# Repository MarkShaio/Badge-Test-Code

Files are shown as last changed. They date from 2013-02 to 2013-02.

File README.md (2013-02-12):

Badge-Test-Code
===============
1.All the code here is from openbeacon except an added section in main.c under MSP430_tag directory. Find the do while loop. 
This is where all the checking code lives in. The code currently in the loop is meant to check the joint between the cpu and the 
accelerometer. This code may not work so you must check.

2.The code in comments in the loop works fine. Basically if you run the code and you see LED2 light up then that means at least one of the pins
from the SPI is not connected properly .

3.debug1.ino will let you check whether your switch is working. The LED on board should toggle along with the switch.

4.In "Latest PCB Version", you will find the most up to date version of my board. If you want to use it there is one thing that you need to 
change. The bottom right corner of the switch must not be covered by the ground plane. So remove the ground plane on the right side
and recreate that ground plane.

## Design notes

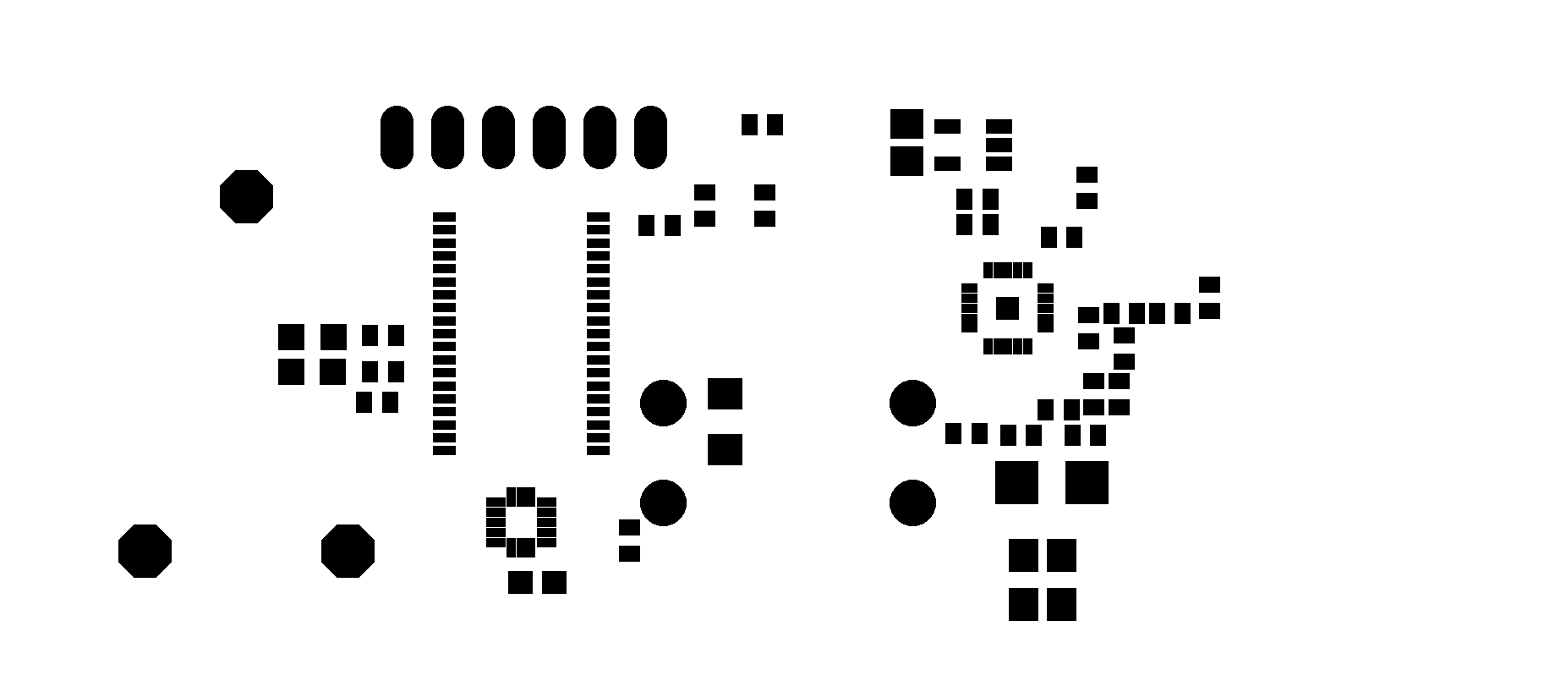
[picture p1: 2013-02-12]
Latest PCB version/With 3D model/eagleUp/eagleUp_nRF24L01-Chip-v12_top_mask.png

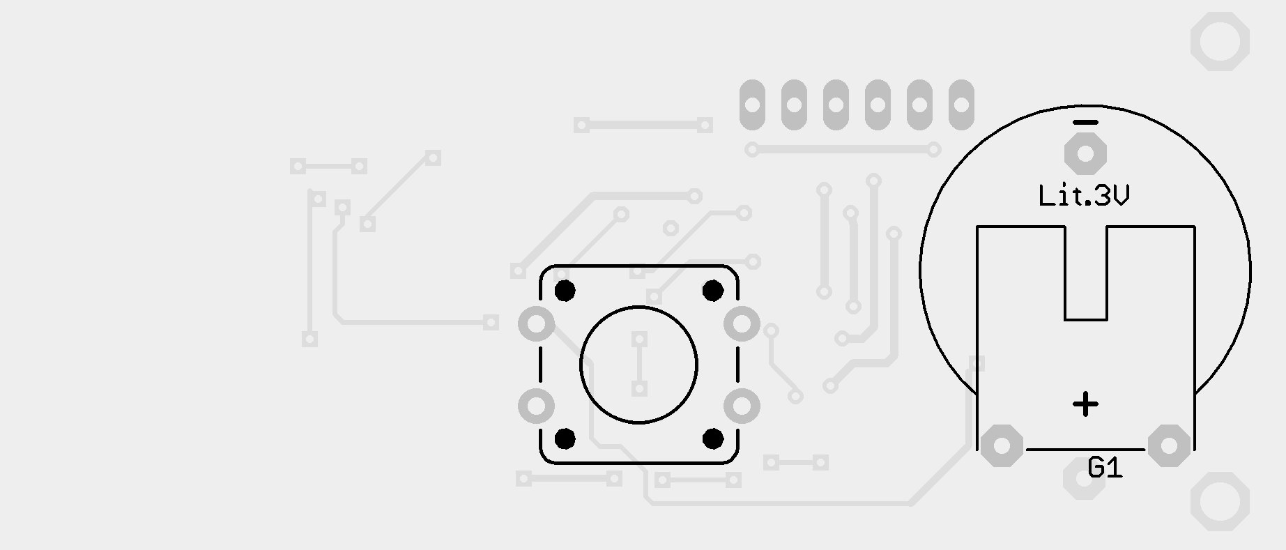
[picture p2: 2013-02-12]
Latest PCB version/With 3D model/eagleUp/eagleUp_nRF24L01-Chip-v12_board_bottom.png

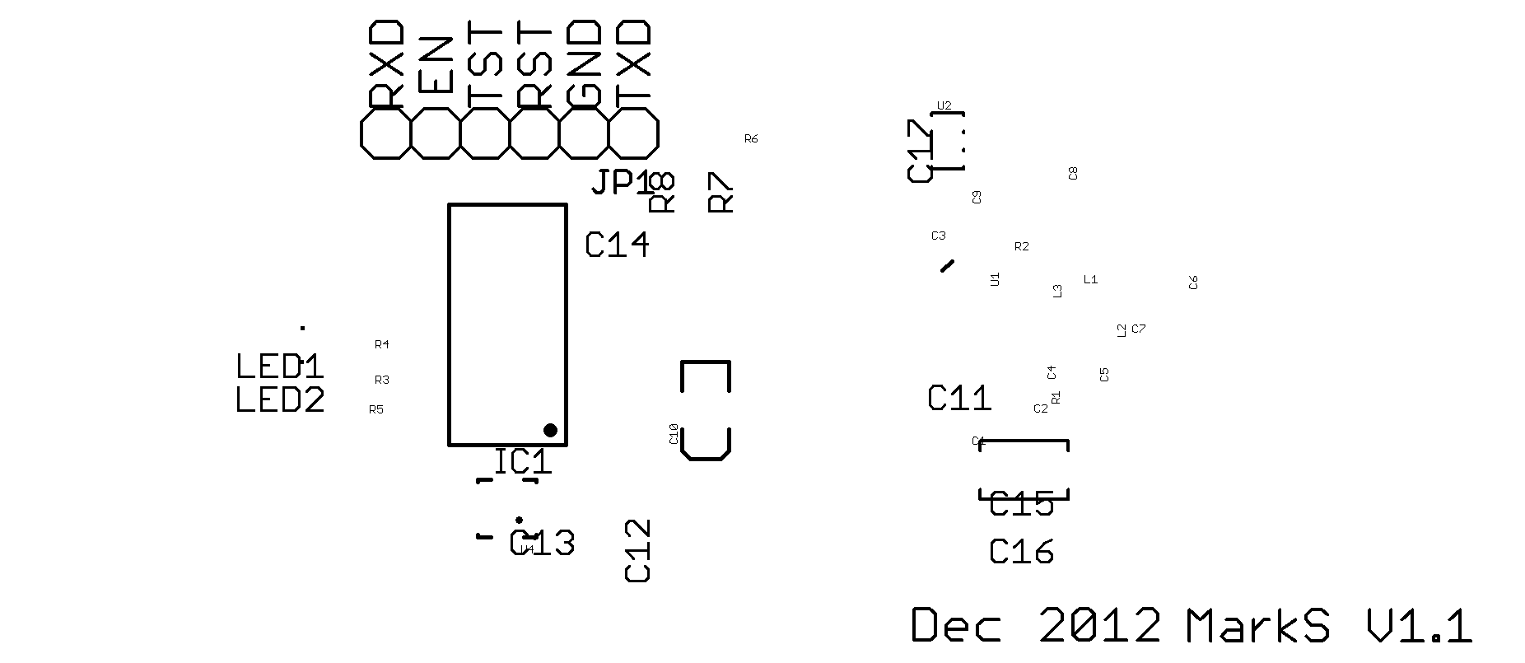
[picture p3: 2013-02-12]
Latest PCB version/With 3D model/eagleUp/eagleUp_nRF24L01-Chip-v12_top_silk.png

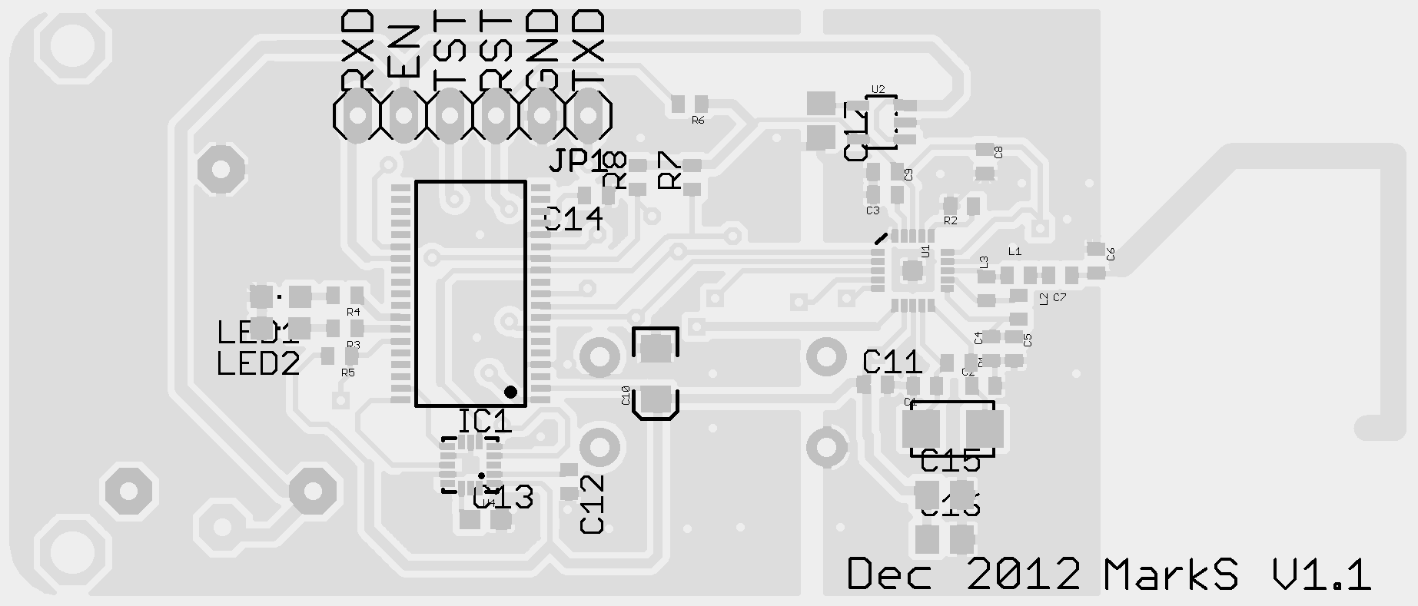
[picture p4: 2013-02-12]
Latest PCB version/With 3D model/eagleUp/eagleUp_nRF24L01-Chip-v12_board_top.png

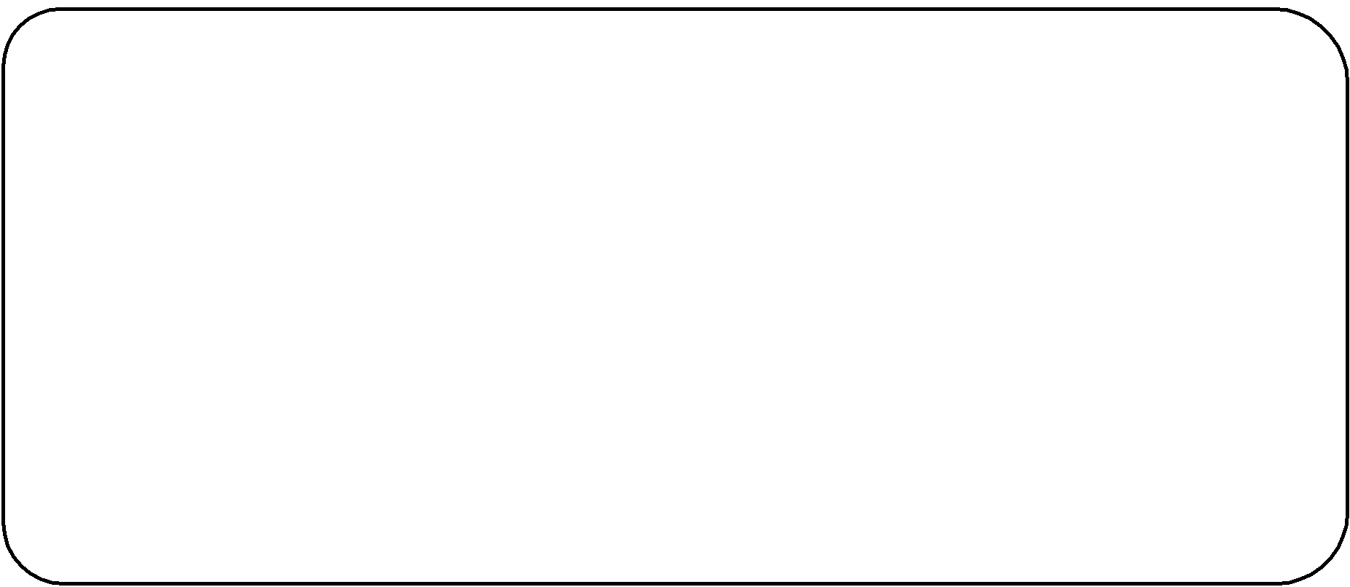
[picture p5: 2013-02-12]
Latest PCB version/With 3D model/eagleUp/eagleUp_nRF24L01-Chip-v12_outline.png

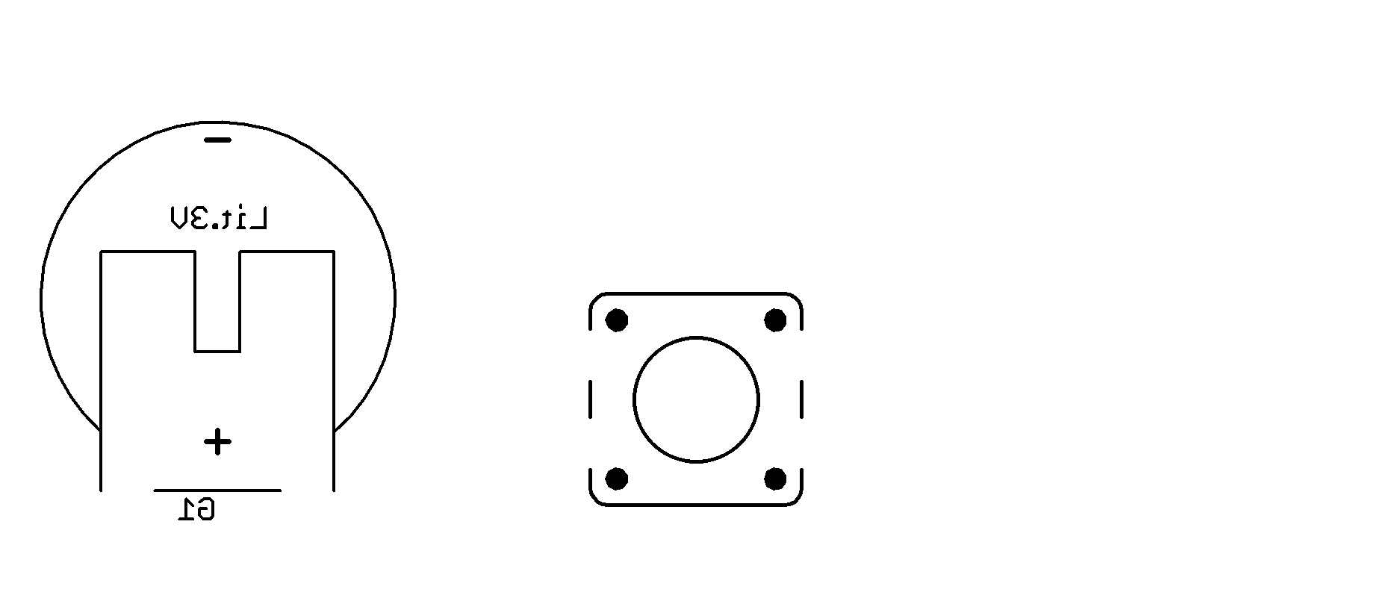
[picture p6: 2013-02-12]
Latest PCB version/With 3D model/eagleUp/eagleUp_nRF24L01-Chip-v12_bottom_silk.png

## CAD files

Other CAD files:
Latest PCB version/With 3D model/3D model.skp

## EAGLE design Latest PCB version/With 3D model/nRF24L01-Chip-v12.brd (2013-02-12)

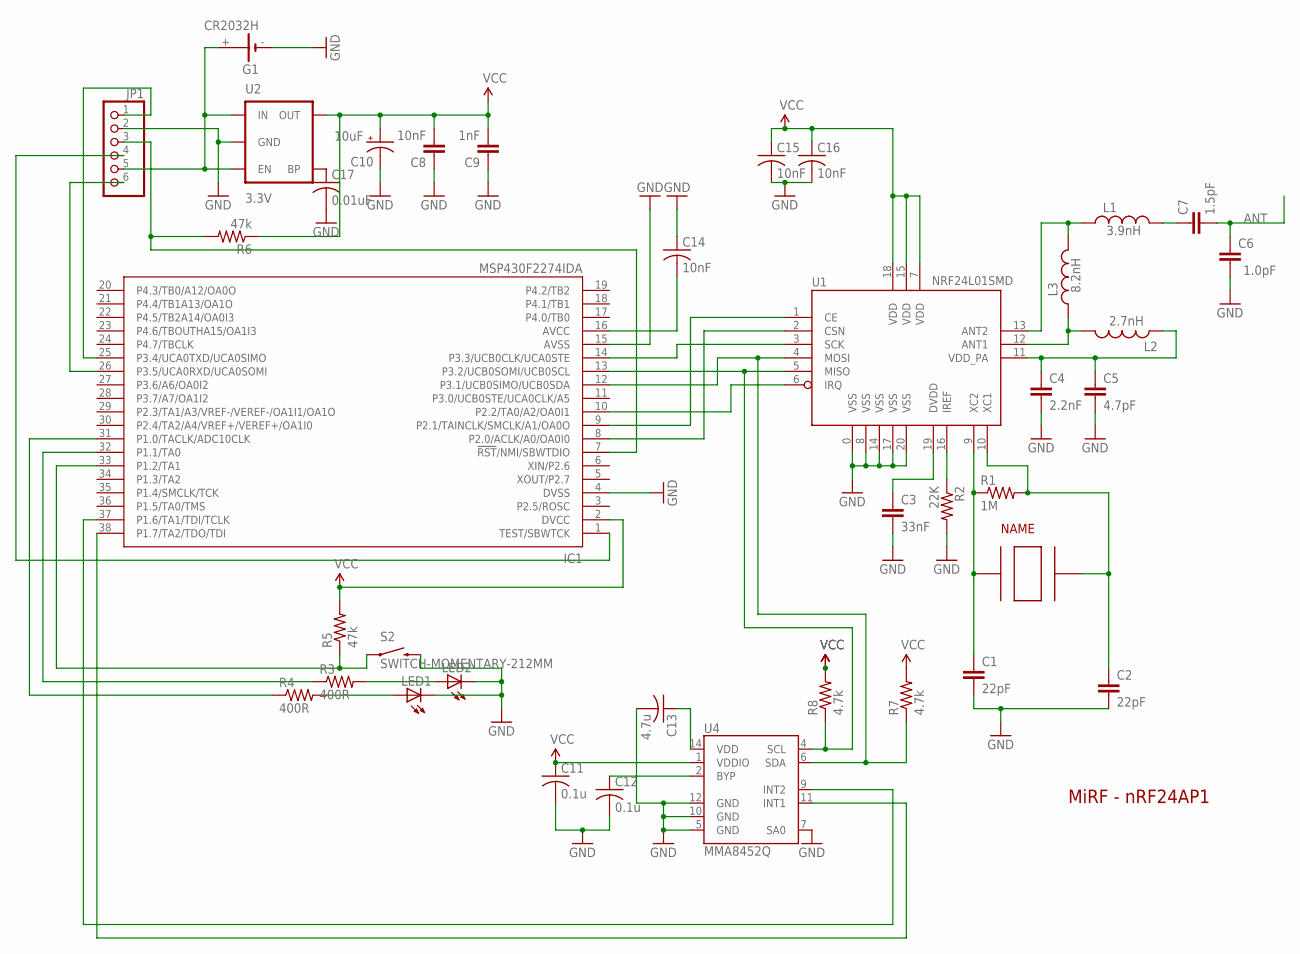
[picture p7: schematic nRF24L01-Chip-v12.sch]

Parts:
C1, C2: 22pF; C0402
C3: 33nF; C0402
C4: 2.2nF; C0402
C5: 4.7pF; C0402
C6: 1.0pF; C0402
C7: 1.5pF; C0402
C8, C14: 10nF; C0402
C9: 1nF; C0402
C10: 10uF; EIA3216
C11, C12: 0.1u; C0402
C13: 4.7u; C0603
C15, C16: 10nF; C0805
C17: 0.01uF; C0805
G1: CR2032H
IC1: MSP430F2274IDA; TSSOP38_R-PDSO-G38-DA
JP1: PINHD-1X6; 1X06
L1: 3.9nH; C0402
L2: 2.7nH; C0402
L3: 8.2nH; C0402
LED1, LED2: LEDCHIPLED_0805; CHIPLED_0805
Q1: SMAQ-5032A; CRSYTAL1
R1: 1M; C0402
R2: 22K; C0402
R3, R4: 400R; C0402
R5, R6: 47k; C0402
R7, R8: 4.7k; R0402
S2: SWITCH-MOMENTARY-212MM; TACTILE-PTH-12MM
U1: NRF24L01SMD; QFN20
U2: 3.3V; SOT23-5
U4: MMA8452Q; QFN-16_0.5MM

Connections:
ANT: C6.2, C7.2
GND: C1.2, C2.2, C3.2, C4.2, C5.2, C6.1, C8.1, C9.1, C10.C (-), C11.2, C12.2, C13.2, C14.1, C15.2, C16.2, C17.2, G1.-, IC1.4 (DVSS), IC1.15 (AVSS), JP1.2, LED1.C, LED2.C, R2.2, S2.3 (2), U1.0 (VSS), U1.8 (VSS), U1.14 (VSS), U1.17 (VSS), U1.20 (VSS), U2.2 (GND), U4.5 (GND), U4.7 (SA0), U4.10 (GND), U4.12 (GND)
unnamed: C1.1, Q1.P$3, R1.1, U1.9 (XC2)
unnamed: IC1.1 (TEST/SBWTCK), JP1.4
unnamed: L2.2, L3.1, U1.12 (ANT1)
unnamed: R2.1, U1.16 (IREF)
unnamed: C3.1, U1.19 (DVDD)
unnamed: L1.1, L3.2, U1.13 (ANT2)
unnamed: C4.1, C5.1, L2.1, U1.11 (VDD_PA)
unnamed: IC1.9 (P2.1/TAINCLK/SMCLK/A1/OA0O), U1.1 (CE)
unnamed: C7.1, L1.2
unnamed: IC1.8 (P2.0/ACLK/A0/OA0I0), U1.2 (CSN)
unnamed: IC1.14 (P3.3/UCB0CLK/UCA0STE), U1.3 (SCK)
unnamed: IC1.12 (P3.1/UCB0SIMO/UCB0SDA), R7.1, U1.4 (MOSI), U4.6 (SDA)
unnamed: IC1.13 (P3.2/UCB0SOMI/UCB0SCL), R8.1, U1.5 (MISO), U4.4 (SCL)
unnamed: IC1.25 (P3.4/UCA0TXD/UCA0SIMO), JP1.1
unnamed: IC1.10 (P2.2/TA0/A2/OA0I1), U1.6 (IRQ)
unnamed: IC1.32 (P1.1/TA0), R3.1
unnamed: LED2.A, R3.2
unnamed: LED1.A, R4.2
unnamed: IC1.33 (P1.2/TA1), R5.1, S2.1
unnamed: C17.1, U2.4 (BP)
unnamed: IC1.26 (P3.5/UCA0RXD/UCA0SOMI), JP1.6
unnamed: C14.2, IC1.16 (AVCC)
unnamed: IC1.31 (P1.0/TACLK/ADC10CLK), R4.1
unnamed: C2.1, Q1.P$4, R1.2, U1.10 (XC1)
unnamed: IC1.7 (!RST!/NMI/SBWTDIO), JP1.3, R6.2
unnamed: C12.1, U4.2 (BYP)
unnamed: IC1.38 (P1.7/TA2/TDO/TDI), U4.11 (INT1)
unnamed: IC1.37 (P1.6/TA1/TDI/TCLK), U4.9 (INT2)
unnamed: C13.1, U4.14 (VDD)
RAW: G1.+, JP1.5, U2.1 (IN), U2.3 (EN)
VCC: C8.2, C9.2, C10.A (+), C11.1, C15.1, C16.1, IC1.2 (DVCC), R5.2, R6.1, R7.2, R8.2, U1.7 (VDD), U1.15 (VDD), U1.18 (VDD), U2.5 (OUT), U4.1 (VDDIO)

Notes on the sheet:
MiRF - nRF24AP1

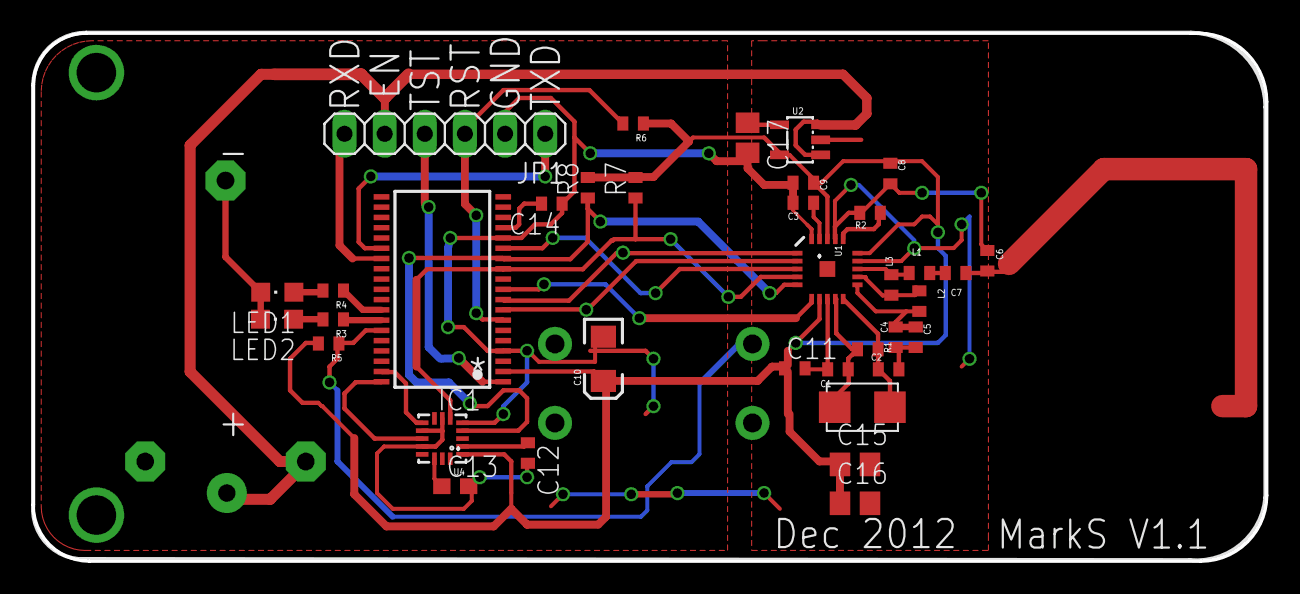
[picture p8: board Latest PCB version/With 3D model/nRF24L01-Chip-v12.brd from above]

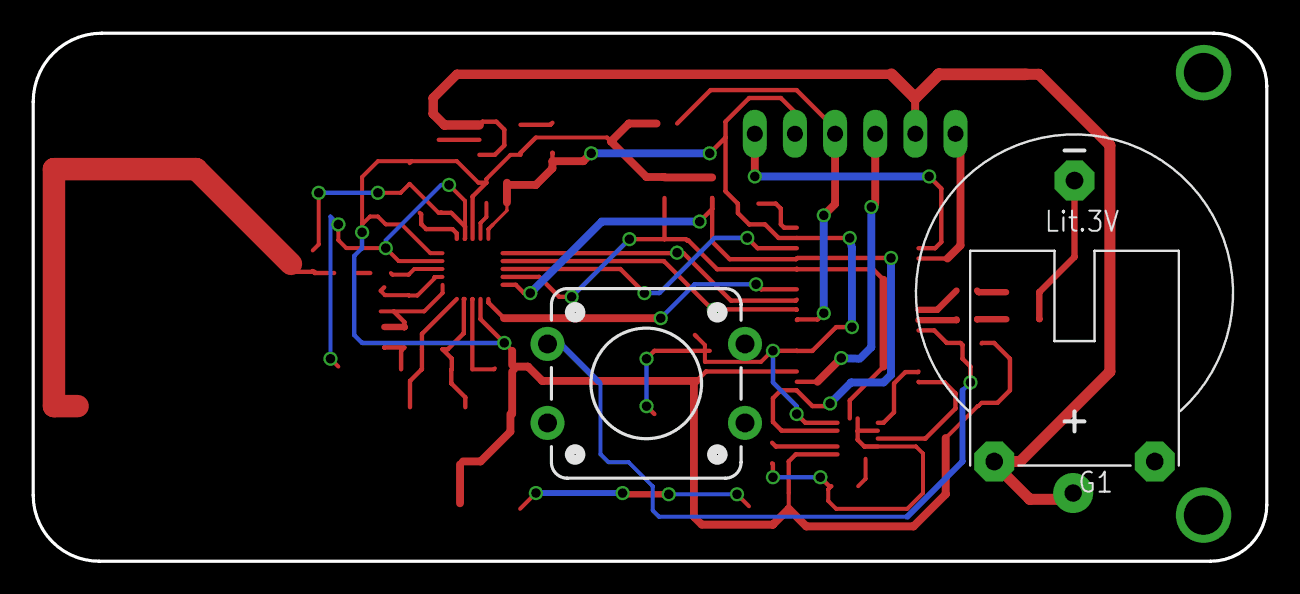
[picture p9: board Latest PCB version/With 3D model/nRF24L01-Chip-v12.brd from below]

Board: 2 copper layers, 78.1 x 33.4 mm, 38 parts (2 on the bottom side), 33 nets.

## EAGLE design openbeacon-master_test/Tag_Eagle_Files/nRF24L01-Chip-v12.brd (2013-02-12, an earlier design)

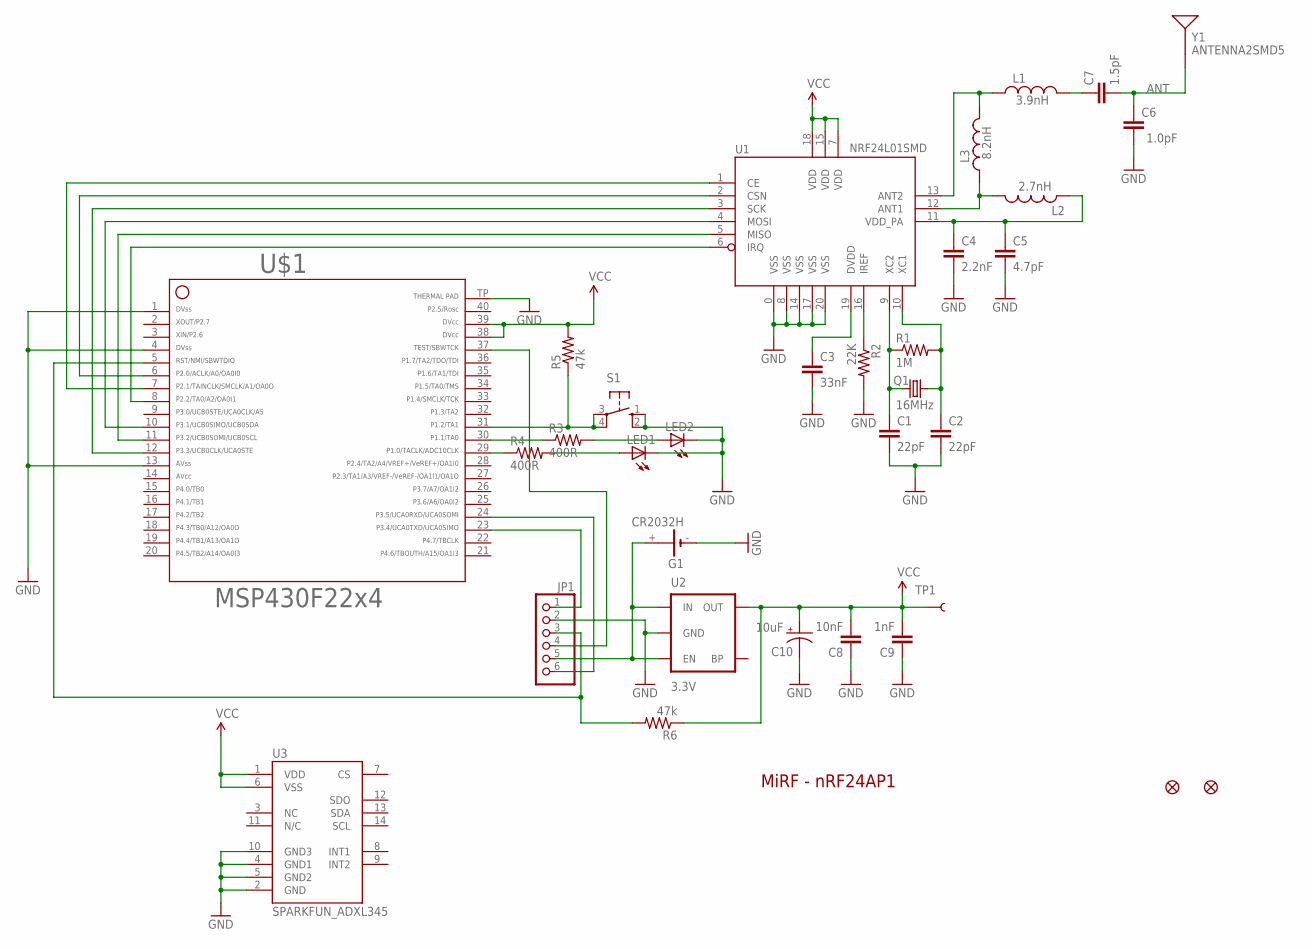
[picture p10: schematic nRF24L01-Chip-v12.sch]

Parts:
C1, C2: 22pF; C0402
C3: 33nF; C0402
C4: 2.2nF; C0402
C5: 4.7pF; C0402
C6: 1.0pF; C0402
C7: 1.5pF; C0402
C8: 10nF; C0402
C9: 1nF; C0402
C10: 10uF; EIA3216
G1: CR2032H
JP1: PINHD-1X6; 1X06
L1: 3.9nH; C0402
L2: 2.7nH; C0402
L3: 8.2nH; C0402
LED1, LED2: LEDCHIPLED_0805; CHIPLED_0805
Q1: 16MHz; CRYSTAL-SMD-5X3
R1: 1M; C0402
R2: 22K; C0402
R3, R4: 400R; C0402
R5, R6: 47k; C0402
S1: 10-XX; B3F-10XX
TP1: TEST-POINT3X5; PAD.03X.05
U1: NRF24L01SMD; QFN20
U2: 3.3V; SOT23-5
U3: SPARKFUN_ADXL345; SPARKFUN_LGA14
U$1: F22X4---RHA40; RHA40
U$2, U$3: FIDUCIAL1X2; FIDUCIAL-1X2
Y1: ANTENNA2SMD5; ANTENNA-CHIP5

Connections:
14: U$1.14
ANT: C6.2, C7.2, Y1.FEED
GND: C1.2, C2.2, C3.2, C4.2, C5.2, C6.1, C8.1, C9.1, C10.C (-), G1.-, JP1.2, LED1.C, LED2.C, R2.2, S1.1 (S), S1.2 (S1), U1.0 (VSS), U1.8 (VSS), U1.14 (VSS), U1.17 (VSS), U1.20 (VSS), U2.2 (GND), U3.2 (GND), U3.4 (GND1), U3.5 (GND2), U3.10 (GND3), U$1.1, U$1.4, U$1.13, U$1.TP
unnamed: C1.1, Q1.1, R1.1, U1.9 (XC2)
unnamed: C2.1, Q1.3 (2), R1.2, U1.10 (XC1)
unnamed: L2.2, L3.1, U1.12 (ANT1)
unnamed: R2.1, U1.16 (IREF)
unnamed: C3.1, U1.19 (DVDD)
unnamed: L1.1, L3.2, U1.13 (ANT2)
unnamed: C4.1, C5.1, L2.1, U1.11 (VDD_PA)
unnamed: U1.4 (MOSI), U$1.10
unnamed: C7.1, L1.2
unnamed: U1.5 (MISO), U$1.11
unnamed: U1.3 (SCK), U$1.12
unnamed: U1.2 (CSN), U$1.6
unnamed: U1.1 (CE), U$1.7
unnamed: R4.1, U$1.29
unnamed: U1.6 (IRQ), U$1.8
unnamed: R3.1, U$1.30
unnamed: LED2.A, R3.2
unnamed: LED1.A, R4.2
unnamed: R5.1, S1.3, S1.4 (P1), U$1.31
unnamed: JP1.1, U$1.23
unnamed: JP1.6, U$1.24
unnamed: JP1.4, U$1.37
unnamed: JP1.3, R6.2, U$1.5
RAW: G1.+, JP1.5, U2.1 (IN), U2.3 (EN)
VCC: C8.2, C9.2, C10.A (+), R5.2, R6.1, TP1.P$1, U1.7 (VDD), U1.15 (VDD), U1.18 (VDD), U2.5 (OUT), U3.1 (VDD), U3.6 (VSS), U$1.38, U$1.39

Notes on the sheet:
MiRF - nRF24AP1

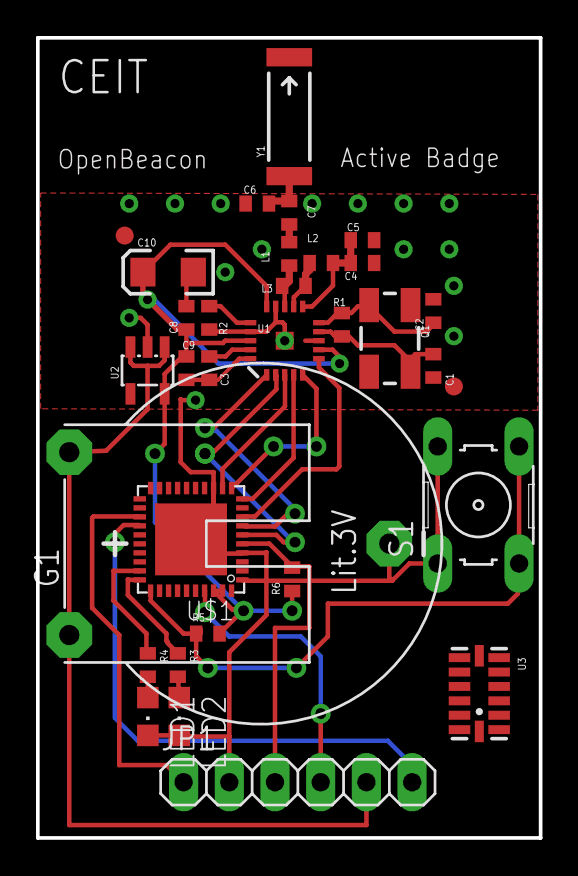
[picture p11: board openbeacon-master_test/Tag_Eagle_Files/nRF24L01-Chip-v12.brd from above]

Board: 2 copper layers, 27.9 x 44.5 mm, 33 parts (1 on the bottom side), 27 nets.

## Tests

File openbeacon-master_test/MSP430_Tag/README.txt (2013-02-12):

This is a fork of the Open-Beacon proximity tag code building on the work of Travis Goodspeed. 

The following pin configuration was used using an ez430-rf2500t and a nRF24l01+. The IRQ pin is not used. Pin configurations can be changed in config.h

       -----------                      -------------
       |         | -- P3.1 ---> MOSI -- |           |
       |         | -- P3.2 ---> MISO -- |           |
       |         | -- P3.3 ---> SCK  -- |           |
       |         | -- P2.0 ---> CSN  -- |           |
       | MSP430  | -- P2.1 ---> CE   -- | nRF24l01+ |
       |         |           NC IRQ  -- |           |
       |         |            $ GND  -- |           |
       |         |            $ VS   -- |           |
       -----------                      -------------

msp430-gcc (open-source) is used to build the program.

You can flash the ez430-rf2500 using mspdebug:
 $ mspdebug rf2500 "prog openbeacontag.hex"

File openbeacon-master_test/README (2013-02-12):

Here are the files used in my low cost deployment of the Openbeacon system. 
Most of the code belongs to their respective owners. This is simply a fork of many repositories which I changed to run on alternate hardware.

Crosstools-ng: These are the settings used to create the toolchain targeting the AT91SAM7 for building the basesation files. This file is used by the crosstool-ng toolchain builder. If it fails to load due to version issues you may have to manually insert the settings by opening the file with a text editor. 

Driver: This is the windows driver for the COM port used by the base station.

MSP430_Tag: These are the files running on the MSP430 together with the nRF24l01+ which make up the tag.

Netduino(at91sam7)_Basestation: This contains the base station code to be run on the netduino together with the nRF24l01+ radio package. 

Node-Server: This is a javascript server run by Node.js which listen on the UDP port for traffic and publishes data on MQTT. 

Openamd-localiser: This is a fork of the localised software used in the opened conference. It has been modified such that it can listen to traffic on MQTT and republish the data back on another MQTT channel.Use options -M and -Q when launching to enable mqtt. Look at 'estimator.c' for more info.

Tag Eagle Files: These are work in progress, non-tested eagle tag files.

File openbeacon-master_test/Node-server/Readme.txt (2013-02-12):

{\rtf1\ansi\ansicpg1252\cocoartf1038\cocoasubrtf360
{\fonttbl\f0\fswiss\fcharset0 Helvetica;}
{\colortbl;\red255\green255\blue255;}
\paperw12240\paperh15840\vieww9000\viewh8400\viewkind0
\pard\tx566\tx1133\tx1700\tx2267\tx2834\tx3401\tx3968\tx4535\tx5102\tx5669\tx6236\tx6803\ql\qnatural\pardirnatural

\f0\fs24 \cf0 This is a UDP server written in Node.js which listens to UDP traffic transmitted by Openbeacon base stations and pushes it to an MQTT channel. \
}

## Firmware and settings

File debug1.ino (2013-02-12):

//#include <Mirf.h>
//#include <MirfHardwareSpiDriver.h>
//#include <MirfSpiDriver.h>
//#include <nRF24L01.h>
//#include <SPI.h>
/*
Turns on LED1 and LED2 is toggled by the switch
 */
 
#define RED_LED P1_0
#define LED2 P1_1
#define BUTTON P1_2
//---------------
#define SS P2_0
#define CE P2_1
#define SCK P3_0
#define MOSI P3_1
#define MISO P3_2
#define IRQ P2_2
//---------------
#define test0 P2_4//random pin that is not connected
#define test1 P1_1//pin that is connected to LED2
//SPI pin configuration


int buttonState = 0;
int val = 0;
void setup() {                
  // initialize the digital pin as an output.
  // Pin 14 has an LED connected on most Arduino boards:
  //Serial.begin(115200);
  //SPI.begin();
  //pinMode(SS,OUTPUT);
  pinMode(test0,INPUT);
  pinMode(test1,INPUT);
  pinMode(CE,OUTPUT);
  pinMode(SS,OUTPUT);
  pinMode(IRQ,OUTPUT);
  pinMode(RED_LED, OUTPUT);
  pinMode(LED2,OUTPUT);  
  pinMode(BUTTON, INPUT);
  //digitalWrite(RED_LED,LOW);
  //digitalWrite(LED2,HIGH);
}

void loop() {
  //Serial.println(bitRead(PORTA,0));
  //val = bitRead(P2OUT,IRQ);
  //digitalWrite(LED2,HIGH);
  //val = P2IN & 0b00000100;
  //digitalWrite(RED_LED,val);
  //P1OUT &= 0b00000001;
  //P1OUT &= 0b00000001;
  //if(val)
    //P1OUT |= 0b00000001;
    //digitalWrite(RED_LED,val);
  //else{
    //P1OUT |= 0b00000000;
 
  //}
 
  
  buttonState = digitalRead(BUTTON);
  if(buttonState == LOW){
    digitalWrite(LED2,HIGH);
  }
  else{
    digitalWrite(LED2,LOW);
    digitalWrite(RED_LED,HIGH);
  }
  //digitalWrite(SS,LOW);
  //SPI.transfer(0);//to send register locaton
  //SPI.transfer(255);//to send value to register
  //digitalWrite(SS,HIGH);
  
  //digitalWrite(RED_LED, HIGH);   // set the LED on
  //delay(1000);              // wait for a second
  //digitalWrite(RED_LED, LOW);    // set the LED off
  //delay(1000);              // wait for a second
}

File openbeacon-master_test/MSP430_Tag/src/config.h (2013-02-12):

/***************************************************************
 *
 * OpenBeacon.org - configuration file
 *
 * Copyright 2006 Milosch Meriac <meriac@openbeacon.de>
 * Modifications in 2010 by Travis Goodspeed <travis at radiantmachines.com>
 *
 ***************************************************************/

/*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
    You should have received a copy of the GNU General Public License along
    with this program; if not, write to the Free Software Foundation, Inc.,
    51 Franklin Street, Fifth Floor, Boston, MA 02110-1301 USA.
    	
*/

#include <signal.h>
#include <io.h>
#include <iomacros.h>


#ifndef CONFIG_H
#define CONFIG_H

#define	CONFIG_DEBUG_LED
#define CONFIG_DELAYUS

	
//TEA is off for now.
//#define CONFIG_TEA_ENABLEENCODE
//#define CONFIG_TEA_ENABLEDECODE

/***************************************************************
 *
 *  CPU peripherals settings
 *
 * configuration:
 *      RA0                     input
 *      RA1     SENSOR          input
 *      RA2     nRF_IRQ         input
 *      RA3     Vpp             input
 *      RA4                     input
 *      RA5                     input
 *
 *      RC0     SCK             output
 *      RC1     MOSI            output
 *      RC2     MISO            input
 *      RC3     CSN             output
 *      RC4     nRF_CE          output
 *      RC5     LED             output
 *
 ***************************************************************/

/*
// PIC pins are weird.  This is deprecated.
#define CONFIG_PIN_SENSOR	RA1
#define CONFIG_PIN_IRQ		RA2

#define CONFIG_PIN_SCK		RC0
#define CONFIG_PIN_MOSI		RC1
#define CONFIG_PIN_MISO		RC2
#define CONFIG_PIN_CSN		RC3
#define CONFIG_PIN_CE		RC4
#define CONFIG_PIN_LED		RC5

#define CONFIG_CPU_XTAL_FREQ	8MHz
#define CONFIG_CPU_TRISA	0x3F
#define CONFIG_CPU_TRISC	0x04
#define CONFIG_CPU_ANSEL	0x00
#define CONFIG_CPU_WPUA		0x02
#define CONFIG_CPU_CMCON0	0x07
#define CONFIG_CPU_OPTION	0x00
#define CONFIG_CPU_OSCCON	0x71
*/

#define PLED P1OUT
#define PLEDDIR P1DIR
#define LEDBITS (BIT0+BIT1+BIT3);
#define LED1_LIT P1OUT&=~BIT0
#define LED2_LIT P1OUT&=~BIT1       // BIT2 --> BIT1
#define LED3_LIT P2OUT&=~BIT2       // LED3 moved to port 2.2
#define LED1_DIM P1OUT|=BIT0
#define LED2_DIM P1OUT	|=BIT1        // BIT2 --> BIT1
#define LED3_DIM P2OUT|=BIT2        // LED3 moved to port 2.2


//Pins and I/O
#define IRQ  BIT0
#define MOSI BIT1
#define MISO BIT2
#define SCK  BIT3

//Moved to port 2 
#define CSN BIT0
#define CE BIT1


#ifdef p3
#define POUT P3OUT
#define PDIR P3DIR
#define PREN P3REN
#define PIN P3IN
#endif

// Port definitions, replacing PICC ones.
#define CONFIG_PIN_CSN_HIGH P2OUT|=CSN;P1OUT|=BIT0		//POUT --> P2OUT
#define CONFIG_PIN_CSN_LOW P2OUT&=~CSN;P1OUT&=~BIT0		//POUT --> P2OUT
#define CONFIG_PIN_CE_HIGH P2OUT|=CE;P1OUT|=BIT1		//POUT --> P2OUT
#define CONFIG_PIN_CE_LOW P2OUT&=~CE;P1OUT&=~BIT1		//POUT --> P2OUT
#define CONFIG_PIN_MOSI_HIGH POUT|=MOSI
#define CONFIG_PIN_MOSI_LOW POUT&=~MOSI
#define CONFIG_PIN_SCK_HIGH POUT|=SCK
#define CONFIG_PIN_SCK_LOW POUT&=~SCK
#define CONFIG_PIN_MISO (PIN&MISO?1:0)

/***************************************************************
 *
 *  RF chip settings
 *
 ***************************************************************/

#define CONFIG_DEFAULT_CHANNEL 81

typedef signed char s_int8_t;

#endif

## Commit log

2013-02-12 initial commit and also mark is silly
    [nRF24L01-Chip-v12.brd, nRF24L01-Chip-v12.sch]
2013-02-12 Added test file for switches.
2013-02-12 File for switch testing
2013-02-12 Changed README content
    [3D model.skp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]

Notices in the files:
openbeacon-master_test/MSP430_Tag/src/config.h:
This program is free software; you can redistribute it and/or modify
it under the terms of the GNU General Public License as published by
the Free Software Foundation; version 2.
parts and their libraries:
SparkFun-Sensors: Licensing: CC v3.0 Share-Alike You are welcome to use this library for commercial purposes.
